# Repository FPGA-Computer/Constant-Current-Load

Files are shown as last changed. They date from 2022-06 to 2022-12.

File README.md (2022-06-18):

## Current Current Load
This is a constant current load useful for a maximum of 50V or 5A or 30W under forced air cooling. A MOSFET with a better package and improve cooling could improve on the upper power limit.

The opamp circuit is powered by an external 12V DC supply. The output current can be set by a 0-0.5V control signal.  The 0.1R 5W power resistor is used with an opamp feedabck loop.

The circuit is constructed on a single side PCB with a mix of SMT and through hole components.  The 10-pin connector is used for controlling and sensing the output.

A low Temperature coefficient sensing resistor with a noninverting amplifier is used for reading the current. It is roughly 0.5V/A intended for a 3.3V microcontroller.  The output gain can be changed by varying R6.

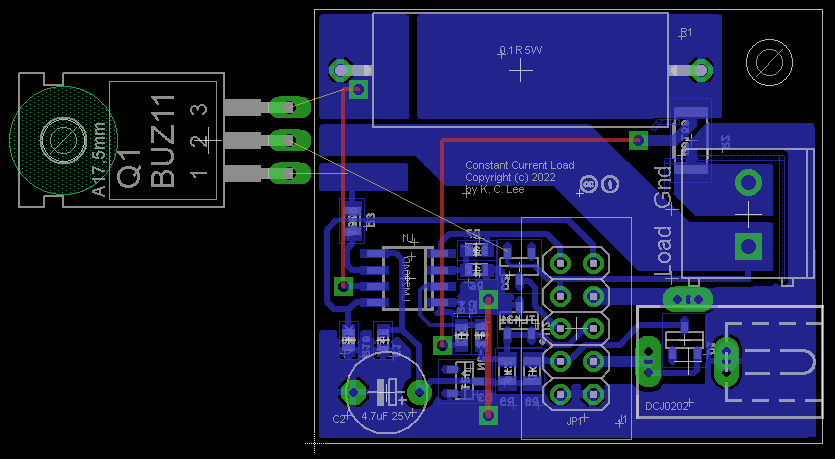
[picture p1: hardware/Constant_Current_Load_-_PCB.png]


The PCB is mounted onto a 50W heatsink with MOSFET and a fan with a speed controller.

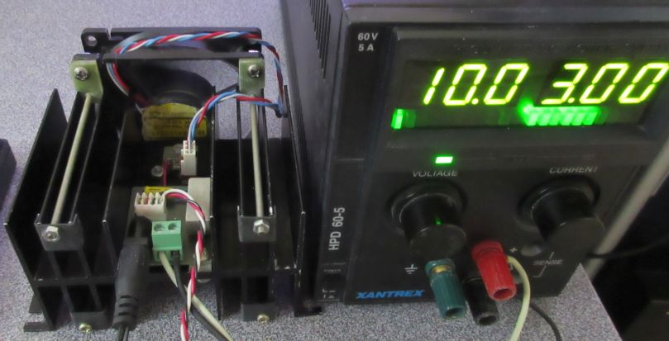
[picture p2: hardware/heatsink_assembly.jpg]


## Fan speed controller

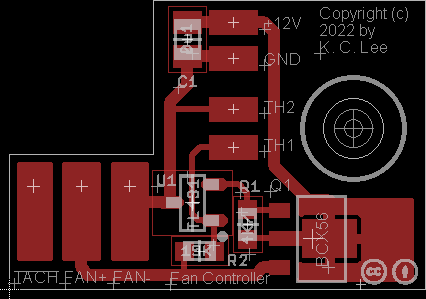
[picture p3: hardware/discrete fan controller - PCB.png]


I have a large bag of 10K thermistors (NTC MF52AT B3950) from aliexpress. The resistance vs temperature is similar to [Fenwal 10K Curve 16](http://techlib.com/electronics/thermistor_data.htm) 

The fan speed controller is a simple linear regulator with a thermistor and a resistor dividor for the voltage feedback. The fan reaches full speed around 45C. The 15K needs to be adjust for a thermistor Beta values other than 3950.

V(fan) = 2.5V * (Rth + 15K)/Rth.

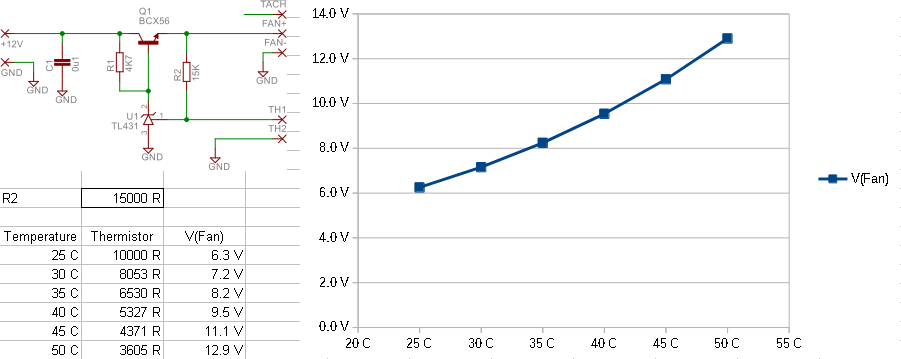
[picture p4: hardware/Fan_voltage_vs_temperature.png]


I really needed a stud mounted part (3D printers) to sense the heatsink temperature, so I made my own.

I filed a hexagon hole in the PCB for a 4-40 hex jackscrew (commonly used for D-sub connectors).

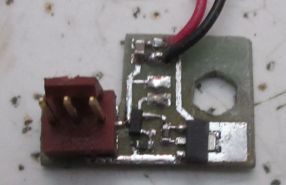
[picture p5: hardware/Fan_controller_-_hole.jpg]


The jackscrew is press fit (or hammered in my case) onto the PCB. The controller PCB is mounted flush onto the heatsink with the base of the stud making good thermal contact. 

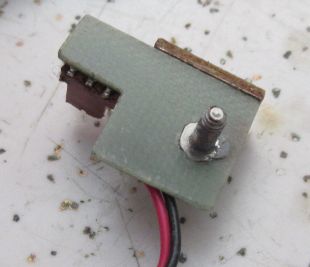
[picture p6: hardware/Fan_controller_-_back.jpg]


I dipped the thermistor in thermal paste and fits into the screw hole. Hot gule or epoxy can then be applied to cover the sensor.  A small piece of PCB (~1cm^2) acts as the heatsink for the transistor.

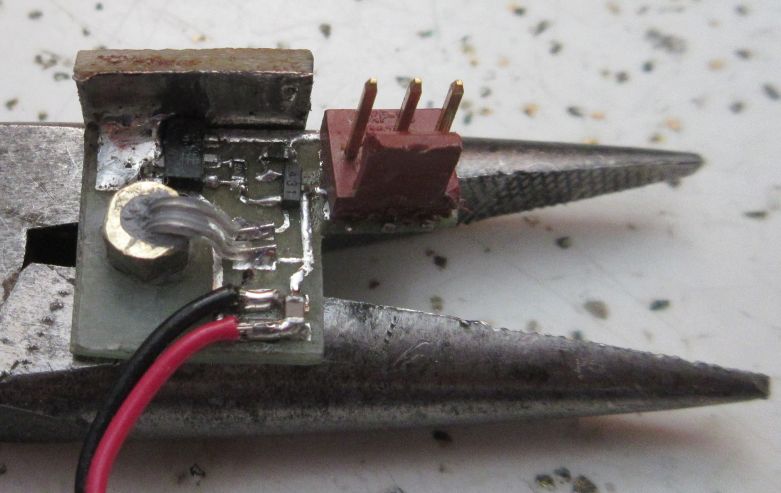
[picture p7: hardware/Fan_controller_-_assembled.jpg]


License: 

Hardware - CC-BY 4.0

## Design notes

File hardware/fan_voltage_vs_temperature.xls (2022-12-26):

R2 | 15000 R
Temperature | Thermistor | V(Fan)
25 C | 10000 R | 6.2 V
30 C | 8053.3 R | 7.2 V
35 C | 6529.5 R | 8.2 V
40 C | 5327.2 R | 9.5 V
45 C | 4370.9 R | 11.1 V
50 C | 3605.3 R | 12.9 V

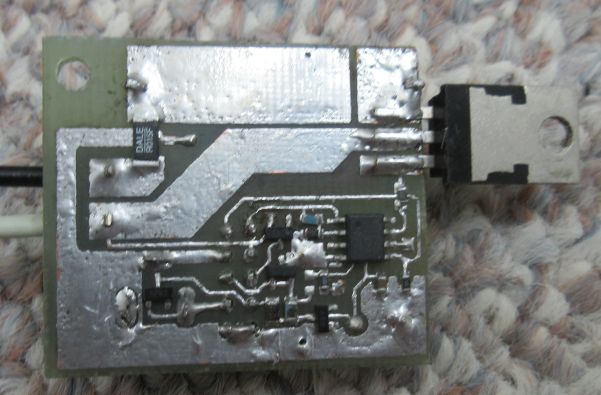
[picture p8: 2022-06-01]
hardware/Constant_Current_Load_PCB_-_Bot.jpg

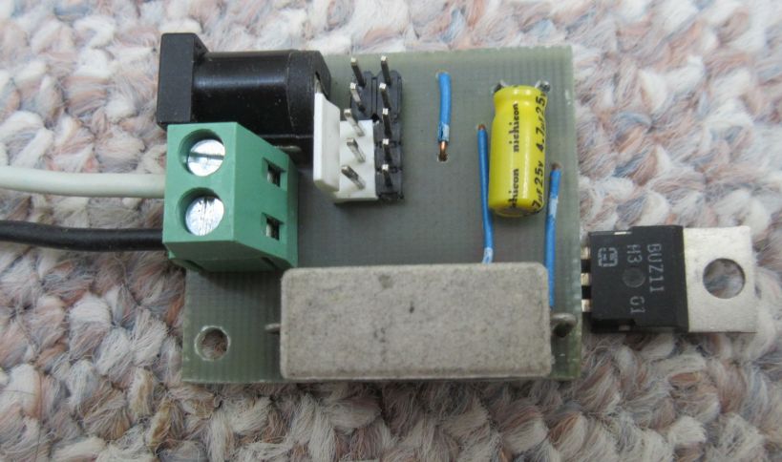
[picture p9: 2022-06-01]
hardware/Constant_Current_Load_PCB_-_Top.jpg

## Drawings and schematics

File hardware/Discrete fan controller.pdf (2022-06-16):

A

A

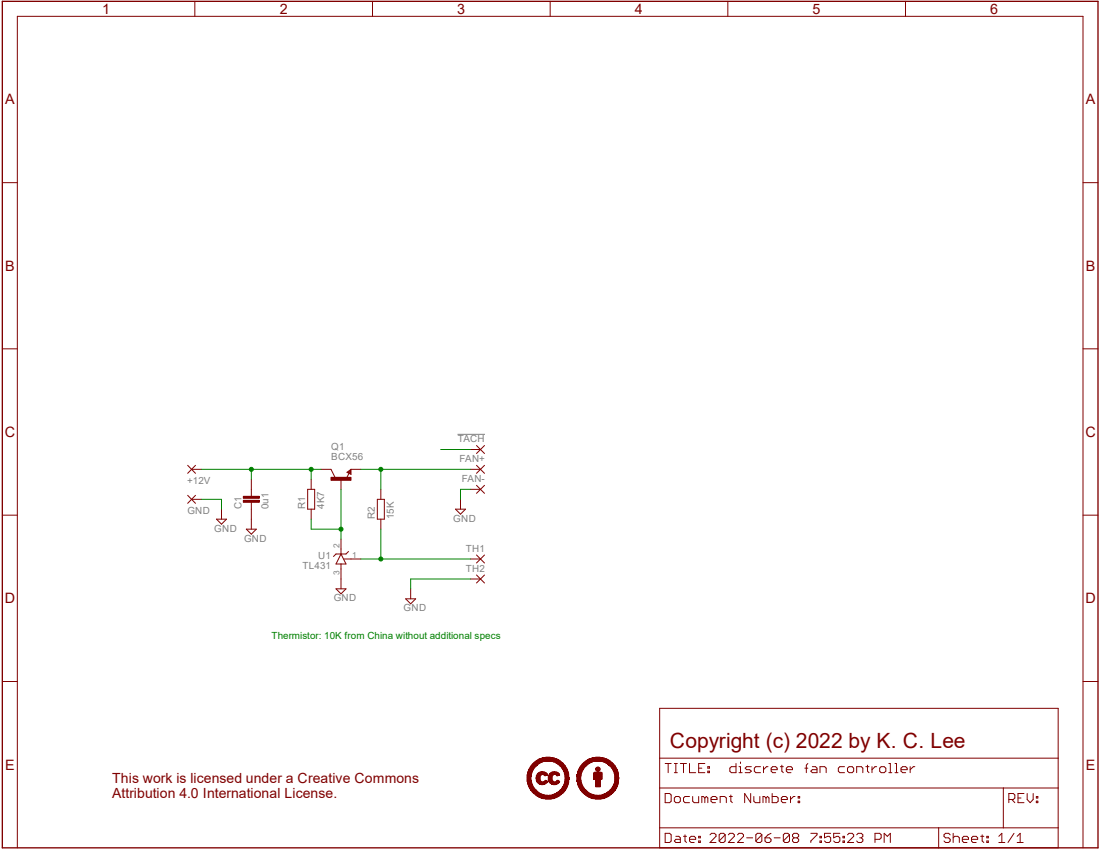
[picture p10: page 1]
BCX56; TL431⁴K⁷; GND; GND ⁰u1; FAN+; TACH; FAN- C¹

Thermistor: 10K from China without additional specs

Copyright (c) 2022 by K. C. Lee

This work is licensed under a Creative Commons
Attribution 4.0 International License.

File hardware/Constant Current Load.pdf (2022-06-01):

1K | NC⁻².2M | 33K 1K 12V

# 2 R²

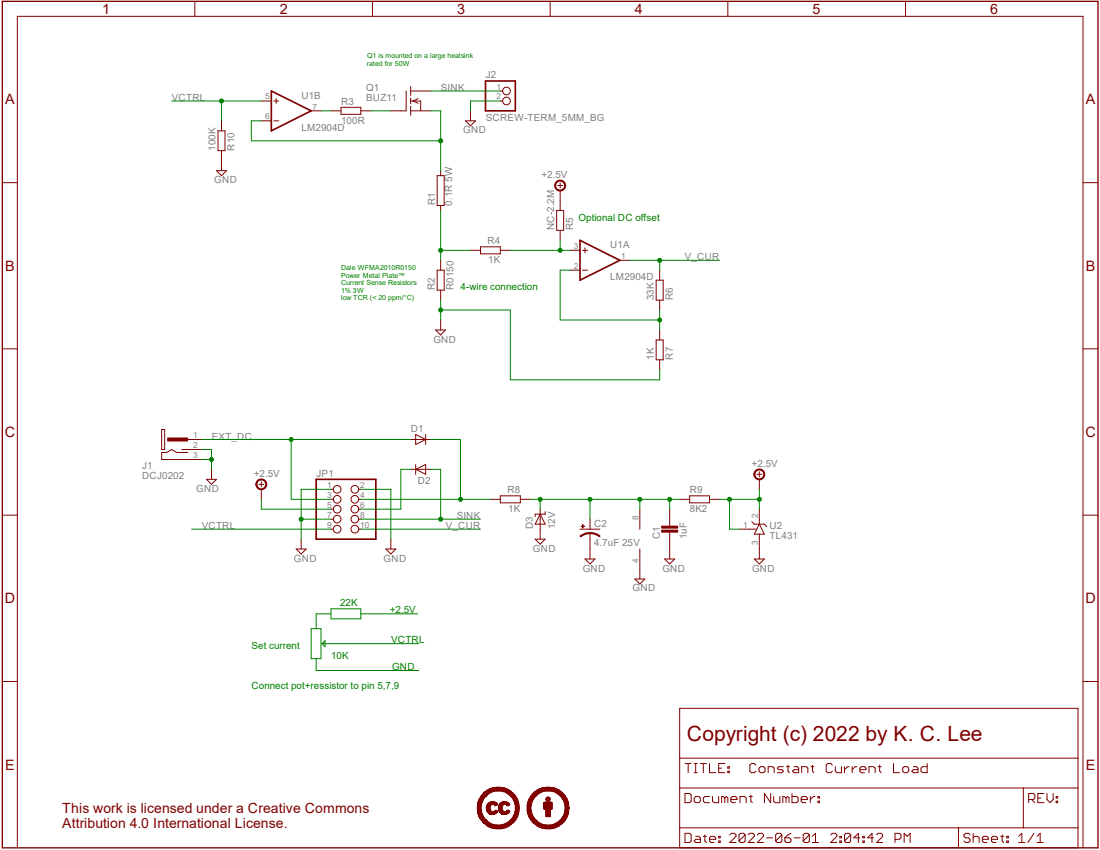
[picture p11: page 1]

Q1 is mounted on a large heatsink
rated for 50W

Dale WFMA2010R0150 Power Metal Plate™ Current Sense Resistors 1% 3W

SINK

Connect pot+ressistor to pin 5,7,9

This work is licensed under a Creative Commons
Attribution 4.0 International License.

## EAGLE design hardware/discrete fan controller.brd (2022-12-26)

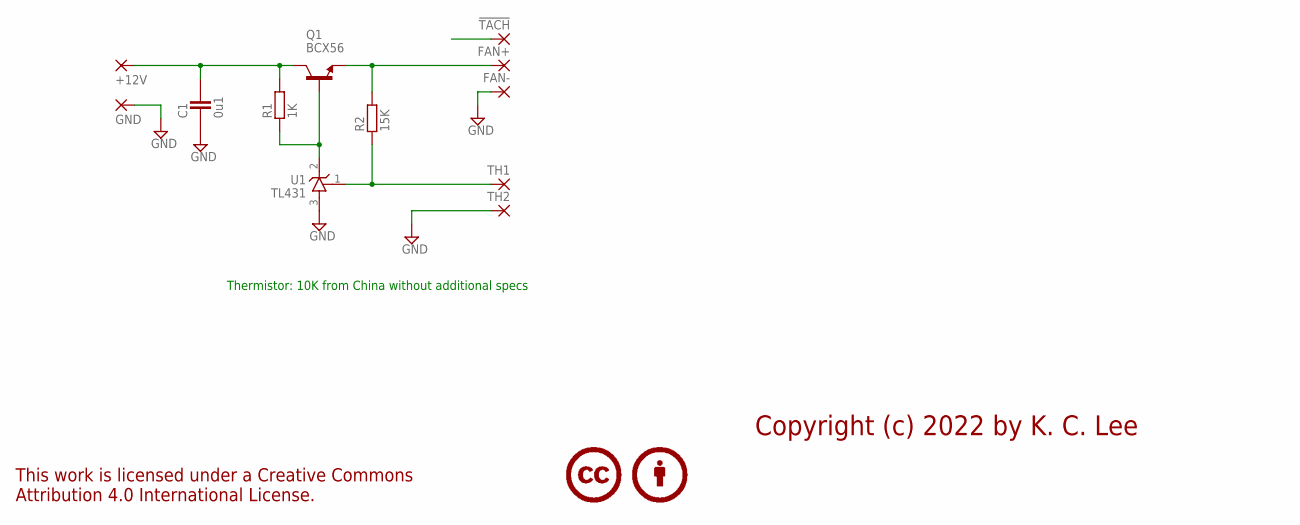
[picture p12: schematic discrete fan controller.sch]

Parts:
!TACH: SMD2; SMD1,27-2,54
+12V: SMD2; SMD1,27-2,54
C1: 0u1; CAPC2012X145AN
FAN+: SMD2; SMD1,27-2,54
FAN-: SMD2; SMD1,27-2,54
GND: SMD2; SMD1,27-2,54
LICENSE1: CC-BY50%; CC-BY-50
Q1: BCX56; SOT89
R1: 1K; RESC1608X55N
R2: 15K; RESC1608X55N
TH1, TH2: SMD2; SMD1,27-2,54
U1: TL431; SOT95P280X135-3N

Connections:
!TACH: !TACH.1
FAN+: FAN+.1, Q1.3 (E), R2.2
GND: C1.1, FAN-.1, GND.1, TH2.1, U1.3 (A)
unnamed: Q1.1 (B), R1.1, U1.2 (C)
unnamed: R2.1, TH1.1, U1.1 (R)
VCC: +12V.1, C1.2, Q1.2 (C), Q1.4 (C), R1.2

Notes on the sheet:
Thermistor: 10K from China without additional specs
Copyright (c) 2022 by K. C. Lee

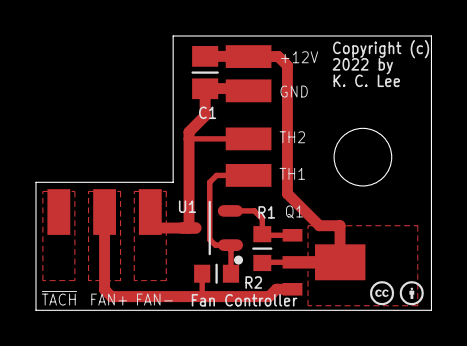
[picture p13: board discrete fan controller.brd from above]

Board: 2 copper layers, 22.0 x 15.2 mm, 13 parts (0 on the bottom side), 5 nets.

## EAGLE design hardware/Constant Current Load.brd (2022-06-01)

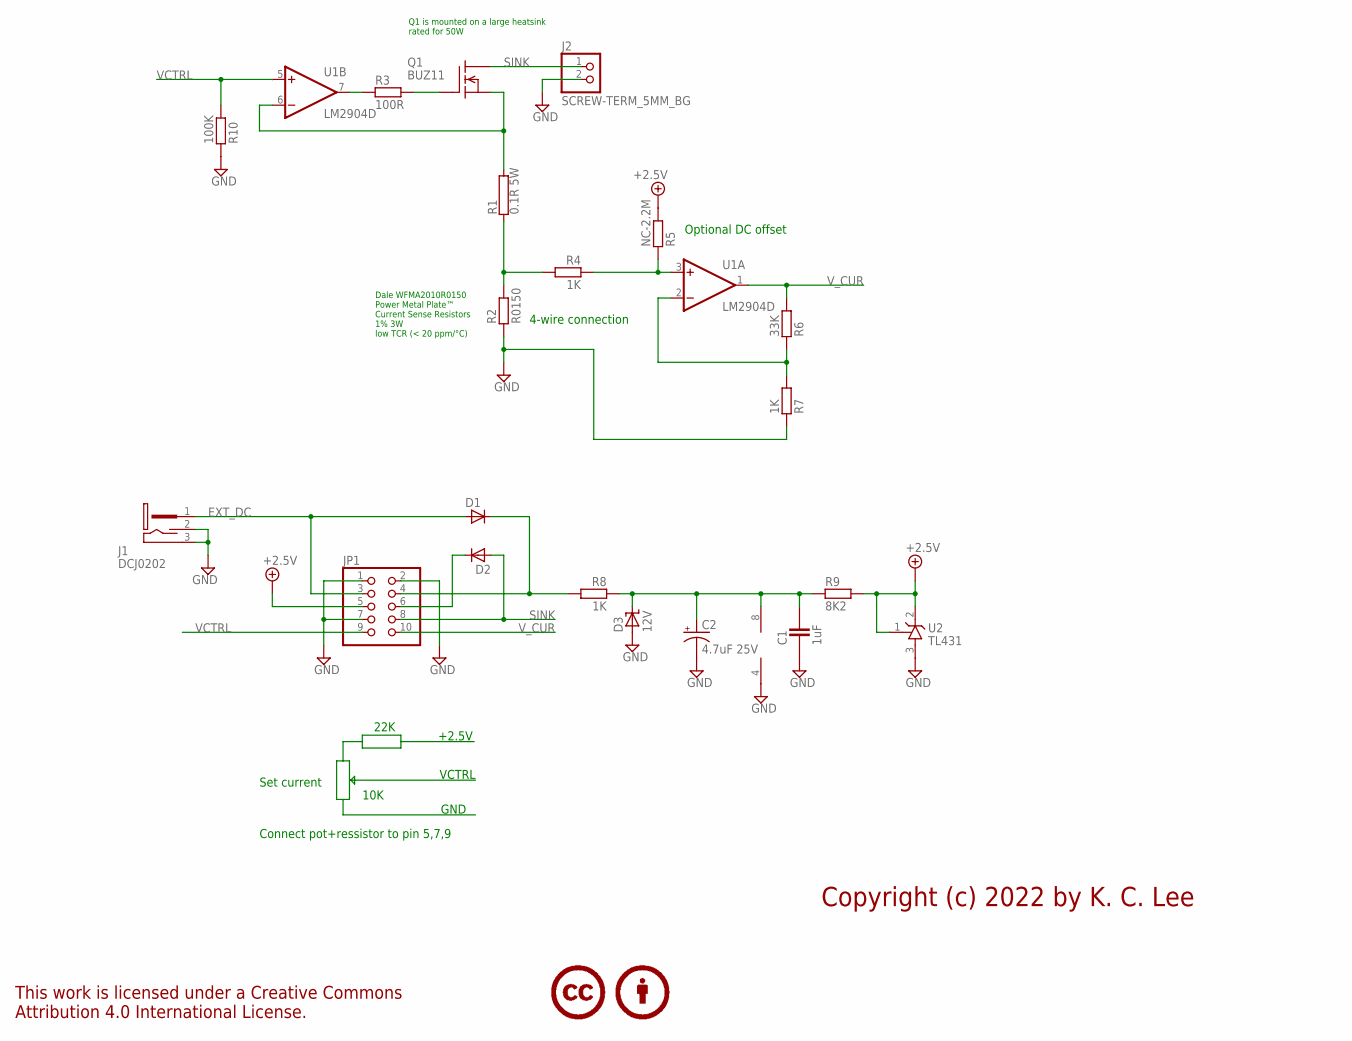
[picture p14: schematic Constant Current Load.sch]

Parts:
C1: 1uF; CAPC1608X92N
C2: 4.7uF 25V; E5-6
D1, D2: DIODE_SOT-23; SOT95P280X135-3N
D3: 12V; SOT95P280X135-3N
J1: DCJ0202; DCJ0202-SLOTTED
J2: SCREW-TERM_5MM_BG; 1X02-5MM-BG
JP1: PINHD-2X5_2.54-W/PLUG; 2X05-W_PLUG
LICENSE1: CC-BY50%; CC-BY-50
Q1: BUZ11; TO220
R1: 0.1R 5W; HPS923
R2: R0150; RESC5025X70N
R3: 100R; RESC2012X70N
R4, R7: 1K; RESC1608X55N
R5: NC-2.2M; RESC1608X55N
R6: 33K; RESC1608X55N
R8: 1K; RESC2012X70N
R9: 8K2; RESC2012X70N
R10: 100K; RESC1608X55N
U1: LM2904D; SO08
U2: TL431; SOT95P280X135-3N

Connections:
+2.5V: JP1.5, R5.2, R9.2, U2.1 (R), U2.2 (C)
EXT_DC: D1.1 (A), J1.1, JP1.3
GND: C1.1, C2.-, D3.1 (A), J1.2, J1.3, J2.2, JP1.1, JP1.2, JP1.7, R2.1, R7.1, R10.1, U1.4 (V-), U2.3 (A)
unnamed: Q1.3 (S), R1.2, U1.6 (-IN)
unnamed: C1.2, C2.+, D3.3 (K), R8.1, R9.1, U1.8 (V+)
unnamed: D2.3 (K), JP1.6
unnamed: Q1.1 (G), R3.2
unnamed: R3.1, U1.7 (OUT)
unnamed: R1.1, R2.2, R4.2
unnamed: R4.1, R5.1, U1.3 (+IN)
unnamed: R6.1, R7.2, U1.2 (-IN)
SINK: D2.1 (A), J2.1, JP1.8, Q1.2 (D)
VCTRL: JP1.9, R10.2, U1.5 (+IN)
V_BUS: D1.3 (K), JP1.4, R8.2
V_CUR: JP1.10, R6.2, U1.1 (OUT)

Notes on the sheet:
4-wire connection
Optional DC offset
Connect pot+ressistor to pin 5,7,9
+2.5V
GND
VCTRL
Set current
Dale WFMA2010R0150 Power Metal Plate™ Current Sense Resistors 1% 3W low TCR (< 20 ppm/°C)
22K
10K
Copyright (c) 2022 by K. C. Lee
Q1 is mounted on a large heatsink rated for 50W

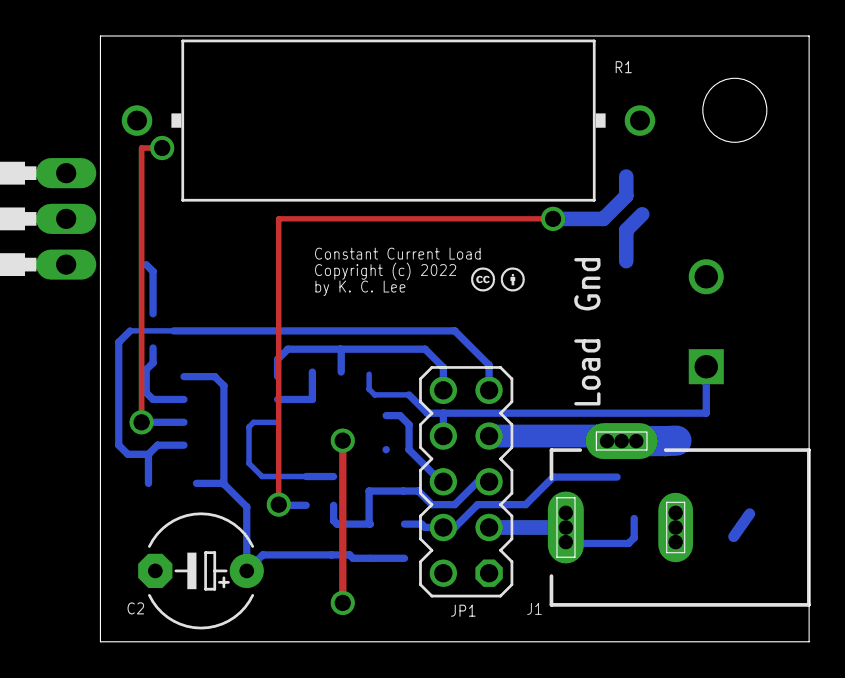
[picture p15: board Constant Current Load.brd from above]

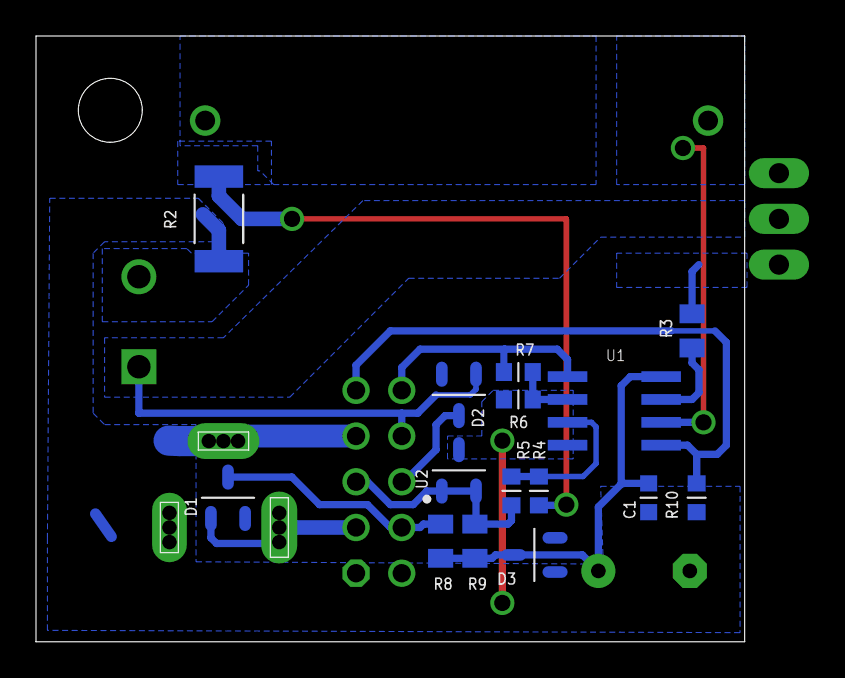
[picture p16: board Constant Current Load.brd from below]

Board: 2 copper layers, 39.4 x 33.7 mm, 22 parts (15 on the bottom side), 15 nets.

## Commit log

2022-06-01 Initial release
    [Constant Current Load.brd, Constant Current Load.sch]
2022-06-08 Power figure revised
    Theta JC for MOSFET is high at 1.67C/W which limits power dissipation
2022-06-16 Added fan speed controller
    [discrete fan controller.brd, discrete fan controller.sch]
2022-06-18 Add fan curve, file name changes
    [fan_voltage_vs_temperature.xls]
2022-12-26 TL431 Minimum current
    4K7 changed to 1K.
    [discrete fan controller.brd, discrete fan controller.sch, fan_voltage_vs_temperature.xls]
